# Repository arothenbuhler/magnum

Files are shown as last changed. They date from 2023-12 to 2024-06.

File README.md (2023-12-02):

# Magnum
Magnum is a development/debug probe supporting SWD and serial communication.

This is not your regular debug probe as it has some neat features that other
debug probes don't provide. Magnum was designed to pack as many useful features
as possible into one small USB-dongle and minimizing the needed cables.

## Pass-through USB
Magnum connects to your PC via a USB-C cable. It has an onboard hub with a
USB-C plug, meaning that if your target also has a USB-C connector, you can
plug Magnum directly into your target. You now get all of the probe
functionality AND the target's USB connection with only a single cable. Due
to the onboard hub, it looks as though Magnum passes the USb connection
straight through.

## Target power managment
When using the target USB-C plug, Magnum can measure power on the VBUS supply
lines. This is useful to do simple power measurements. If the measurement
bandwidth is not high enough or if one simply want to "look" at the current as
a waveform (i.e. with a scope), there is an analog output that can be directly
connected to a scope or other analog measurement device. This analog output
reflects the real-time measured current as a voltage.

Additionally, Magnum allows to control the target's power using a load switch.
The USB hub has control over this too, so in normal operation if the host
detects an issue and attempts to reset the device, the hub's power control pin
will cycle target power. This can of course interfere with debugging and so
Magnum allows to override the hub's power control so the user can dictate when
power to the target is on or off. The default configuration is to let the USB
hub (and therefore the host) control the power state.

## Integrated serial port
A lot of debug probes don't provide an extra serial port. Not Magnum, it
integrates a debug serial port and makes it available on the same USB interface
with all other probe functionality. This serial port is part of the 10-pin
debug connector along with SWD and SWO.

One of the key differentiators, however, is that this debug serial port is also
mapped onto the target's USB-C connector's SBU lines. The SBU lines are not
defined in the USB-C specification and can be used/defined by the device
manufacturer. This means that if the target device connects its debug UART
signals to the SBU lines, then Magnum can act as a simple serial dongle with no
extra cables needed. It goes without saying that this also implies that the
debug UART lines can now be accessed without opening the target's enclosure.

Magnum uses the USB-C connector's CC lines to detect the connector orientation
and then automatically swaps the Rx/Tx signals.

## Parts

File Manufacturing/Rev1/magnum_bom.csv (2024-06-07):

Comment | Designator | Footprint | LCSC
18pF | C1,C2,C17,C21 | Redhill_lib:C_0402_1005Metric | C1549
0.1uF | C3,C4,C5,C6,C7,C8,C12,C13,C14,C16,C22,C23,C24,C25,C26,C27,C28,C30,C31,C32,C33 | Redhill_lib:C_0402_1005Metric | C1525
1nF | C35,C36 | Redhill_lib:C_0402_1005Metric | C1523
1uF | C18,C19,C20,C29,C34,C37,C38,C40,C42,C43 | Redhill_lib:C_0402_1005Metric | C52923
10uF | C9,C10,C11,C15,C39,C41 | Redhill_lib:C_0603_1608Metric | C96446
LTST-C190GKT | D2 | Redhill_lib:LED_0603_1608Metric | C125093
LTST-C190KFKT | D3 | Redhill_lib:LED_0603_1608Metric | C157740
LTST-C190TBKT | D4 | Redhill_lib:LED_0603_1608Metric | C125096
DT1240A-08LP3810 | D5 | Redhill_lib:UDFN-9_1.0x3.8mm_P0.5mm | C526598
SP0504BAJT | D6,D7 | Redhill_lib:SOT-353_SC-70-5 | C5116451
LED_DUAL_RED_GREEN_LTST-C235KGKRKT | D8 | Redhill_lib:LED_LiteOn_LTST-C155GEKT | C913080
6A, 33Ohm @100MHz | FB1,FB2 | Redhill_lib:R_1206_3216Metric | C74090
BLM15AG601SN1D | FB3,FB4,FB5,FB6,FB7,FB8 | Redhill_lib:R_0402_1005Metric | C76884
MountingHole | H1,H2 | MountingHole:MountingHole_2.5mm
USB_C_Receptacle_USB2.0 | J1 | Redhill_lib:USB_C_Receptacle_GCT_USB4105-xx-A_16P_TopMnt_Horizontal | C3025063
CONN_Header_2Pin_2.54mmPitch | J3 | Redhill_lib:Header_2Pin_Pitch2.54mm_Drill0.8mm | C5116481
CONN_USB4155_USB_C_Plug | J5 | Redhill_lib:GCT_USB4155-03-C_REVA | C5183853
ARM_SWD_SERIAL_10 | J4,J6 | Redhill_lib:PinHeader_2x05_P1.27mm_Vertical_SMD | C2874168
2N7002 | Q1,Q2,Q3,Q4 | Redhill_lib:SOT-23 | C5224215
1M | R1 | Redhill_lib:R_0402_1005Metric | C138033
27 | R12,R13,R21 | Redhill_lib:R_0402_1005Metric | C5151586
100 | R16,R17,R19,R25,R29,R52 | Redhill_lib:R_0402_1005Metric | C471762
0 | R2 | Redhill_lib:R_0402_1005Metric | C17168
56k | R3,R4,R6,R22,R44,R51 | Redhill_lib:R_0402_1005Metric | C25796
0.02 | R30 | Redhill_lib:R_1206_3216Metric | C2889962
51 | R9,R10,R24,R32,R33,R34,R35,R36,R37,R41,R42,R43,R47,R48 | Redhill_lib:R_0402_1005Metric | C2759480
12k | R5,R14,R15 | Redhill_lib:R_0402_1005Metric | C25752
10k | R7,R8,R11,R18,R20,R23,R26,R27,R28,R31,R38,R39,R40,R45,R46,R49,R50 | Redhill_lib:R_0402_1005Metric | C25744
EMI2121MTTAG | U1,U9 | Redhill_lib:WDFN-8-1EP_2x2.2mm_P0.5mm_EP0.80x0.54 | C464146
FUSB302BMPX | U10 | Redhill_lib:WQFN-14-1EP_2.5x2.5mm_P0.5mm_EP1.45x1.45mm | C132291
FUSB303BTMX | U11 | Redhill_lib:Texas_X2QFN-12_1.6x1.6mm_P0.4mm
IC_MEM_AT24CSW010-STUM-T | U12 | Redhill_lib:SOT-23-5 | C5224830
IC_USB2412-DZK | U2 | Redhill_lib:QFN-28-1EP_5x5mm_P0.5mm_EP3.35x3.35mm_ThermalVias | C220647
3.3V, 300mA | U3 | Redhill_lib:TSOP-5_1.65x3.05mm_P0.95mm | C603505
W25Q32JVZP | U4 | Redhill_lib:USON-8_2x3mm | C2843335
RP2040 | U5 | Redhill_lib:QFN-56-1EP_7x7mm_P0.4mm_EP3.2x3.2mm_ThermalVias | C2040
IC_INA225 | U6 | Redhill_lib:VSSOP-8_3.0x3.0mm_P0.65mm | C485974
AP22814AW5 | U7 | Redhill_lib:SOT-23-5 | C2680321
IC_FSUSB42MUX | U8 | Redhill_lib:MSOP-10_3x3mm_P0.5mm | C11355
24MHz | Y1 | Redhill_lib:Crystal_SMD_0603-4Pin_6.0x3.5mm | C2449842
Crystal_ECS-120-20-33_12MHz | Y2 | Redhill_lib:Crystal_SMD_3225-4Pin_3.2x2.5mm | C9002

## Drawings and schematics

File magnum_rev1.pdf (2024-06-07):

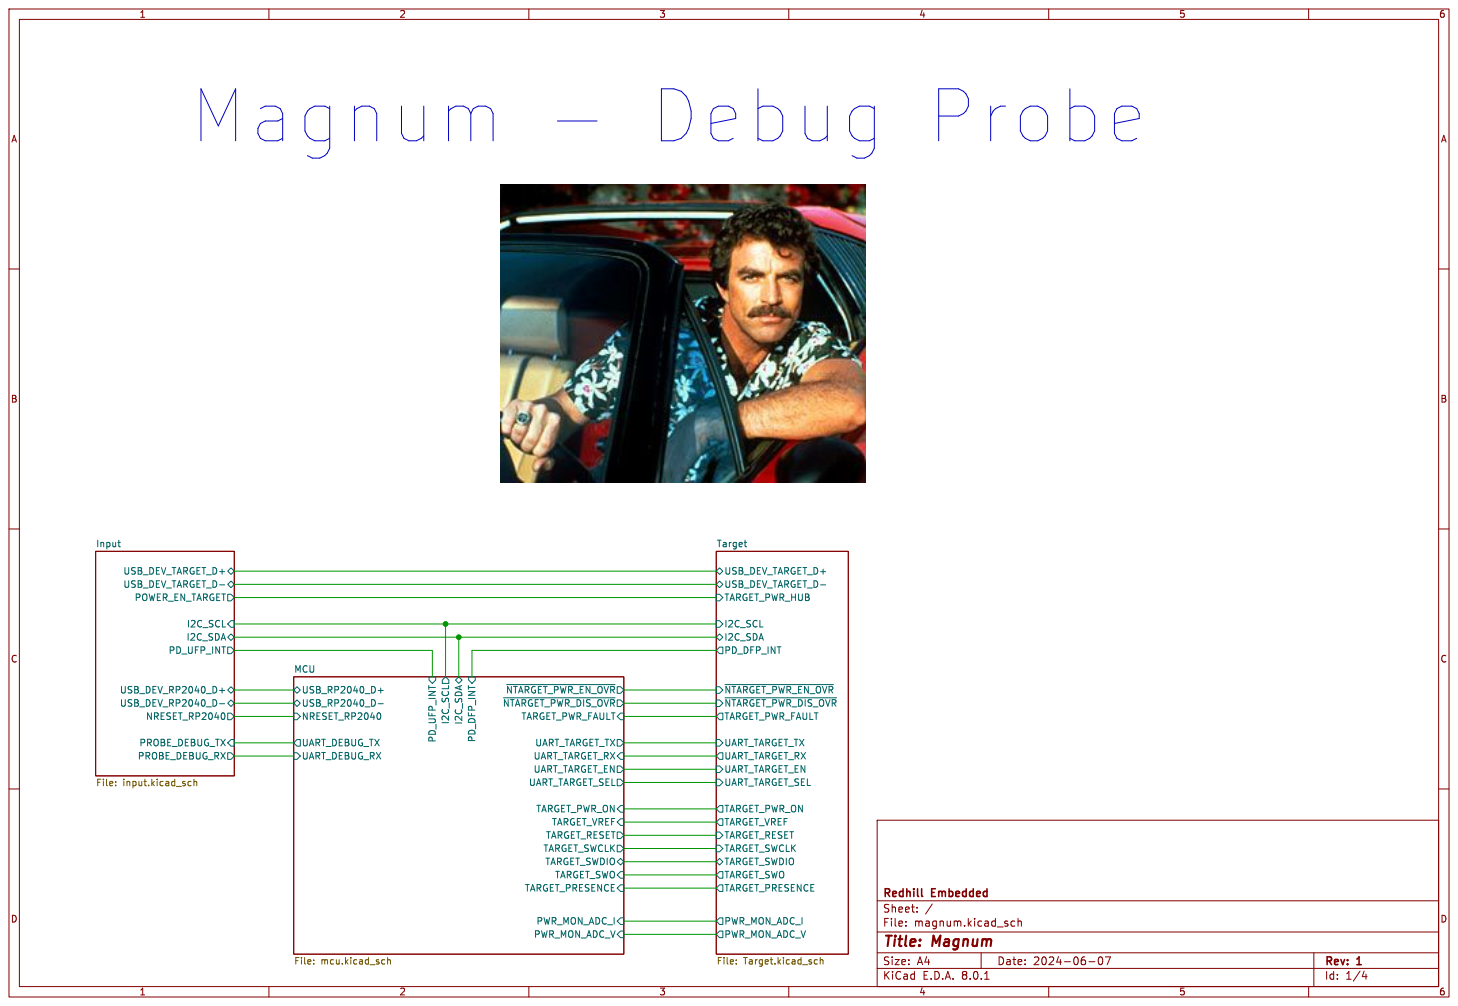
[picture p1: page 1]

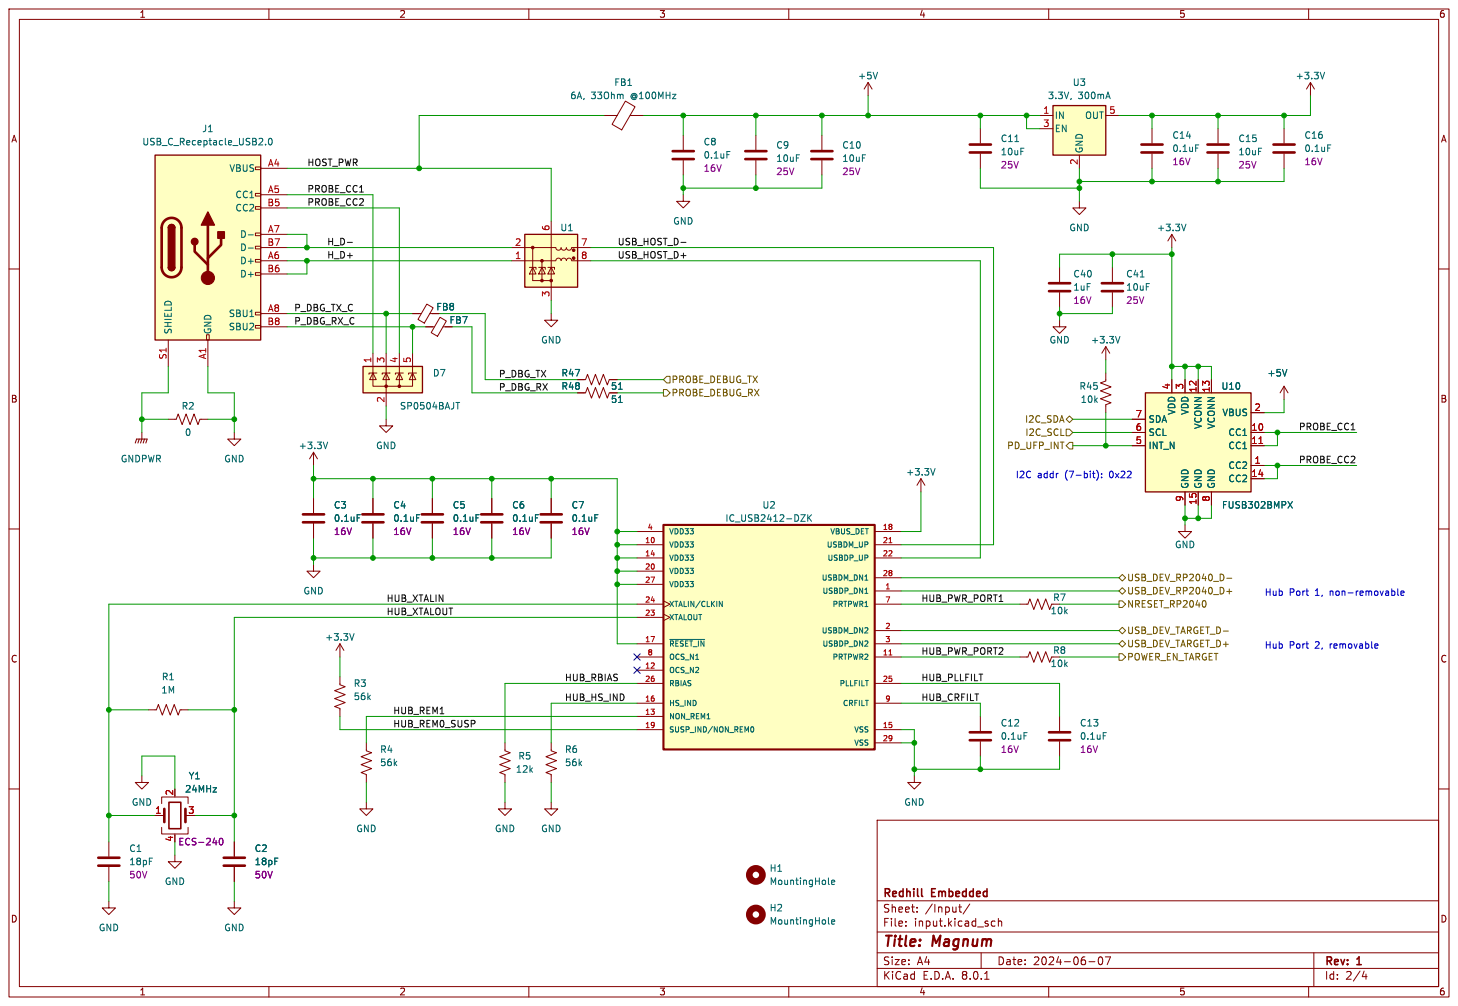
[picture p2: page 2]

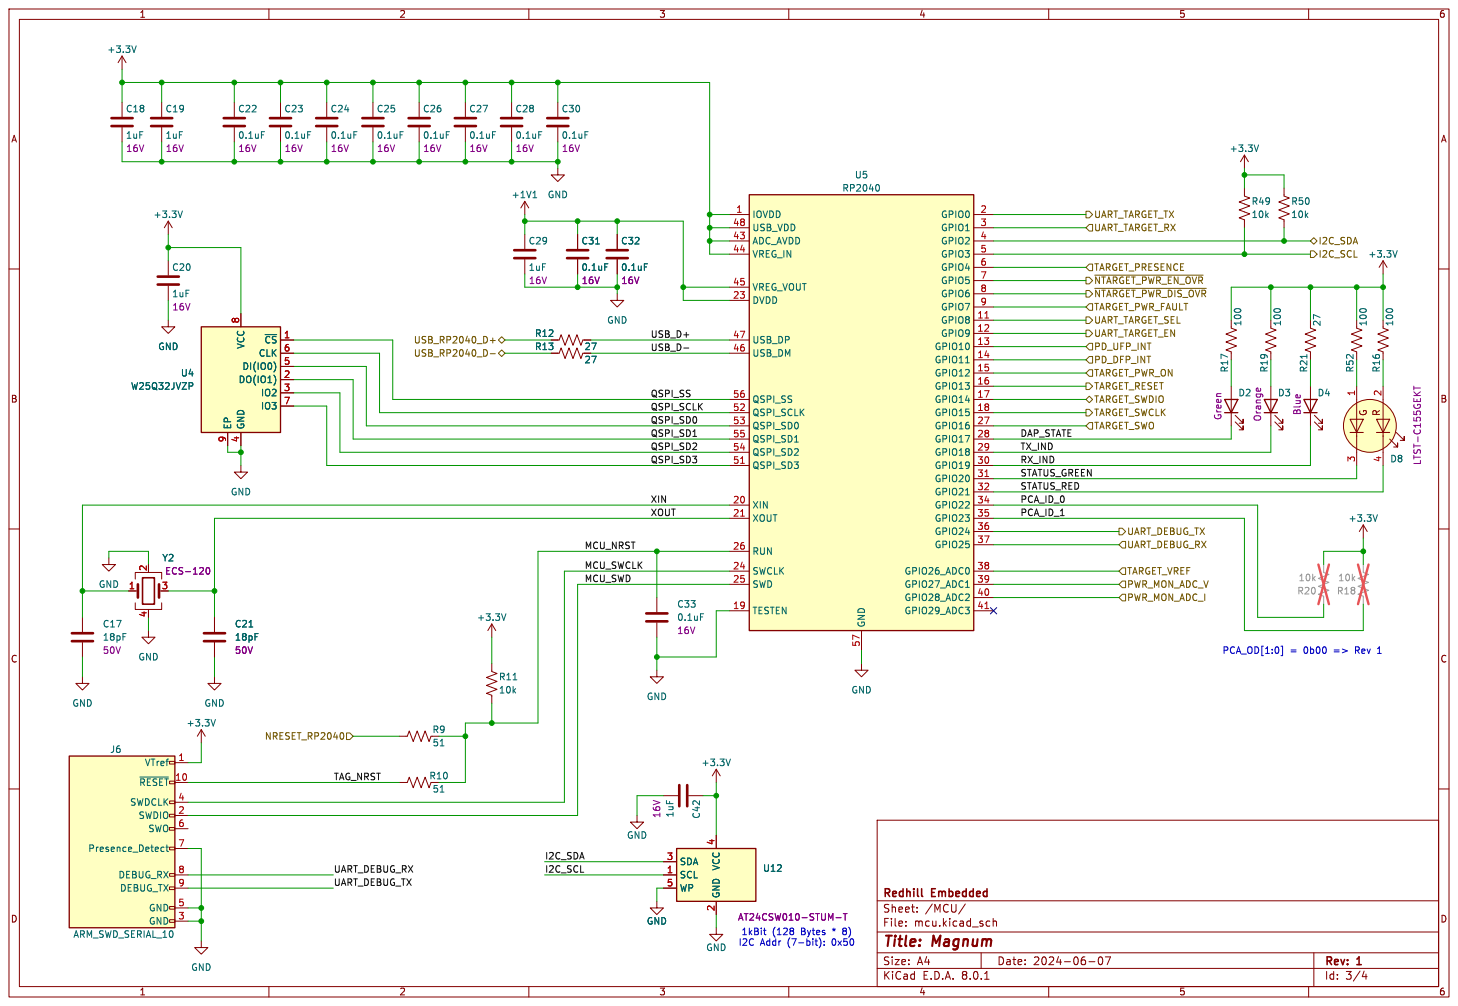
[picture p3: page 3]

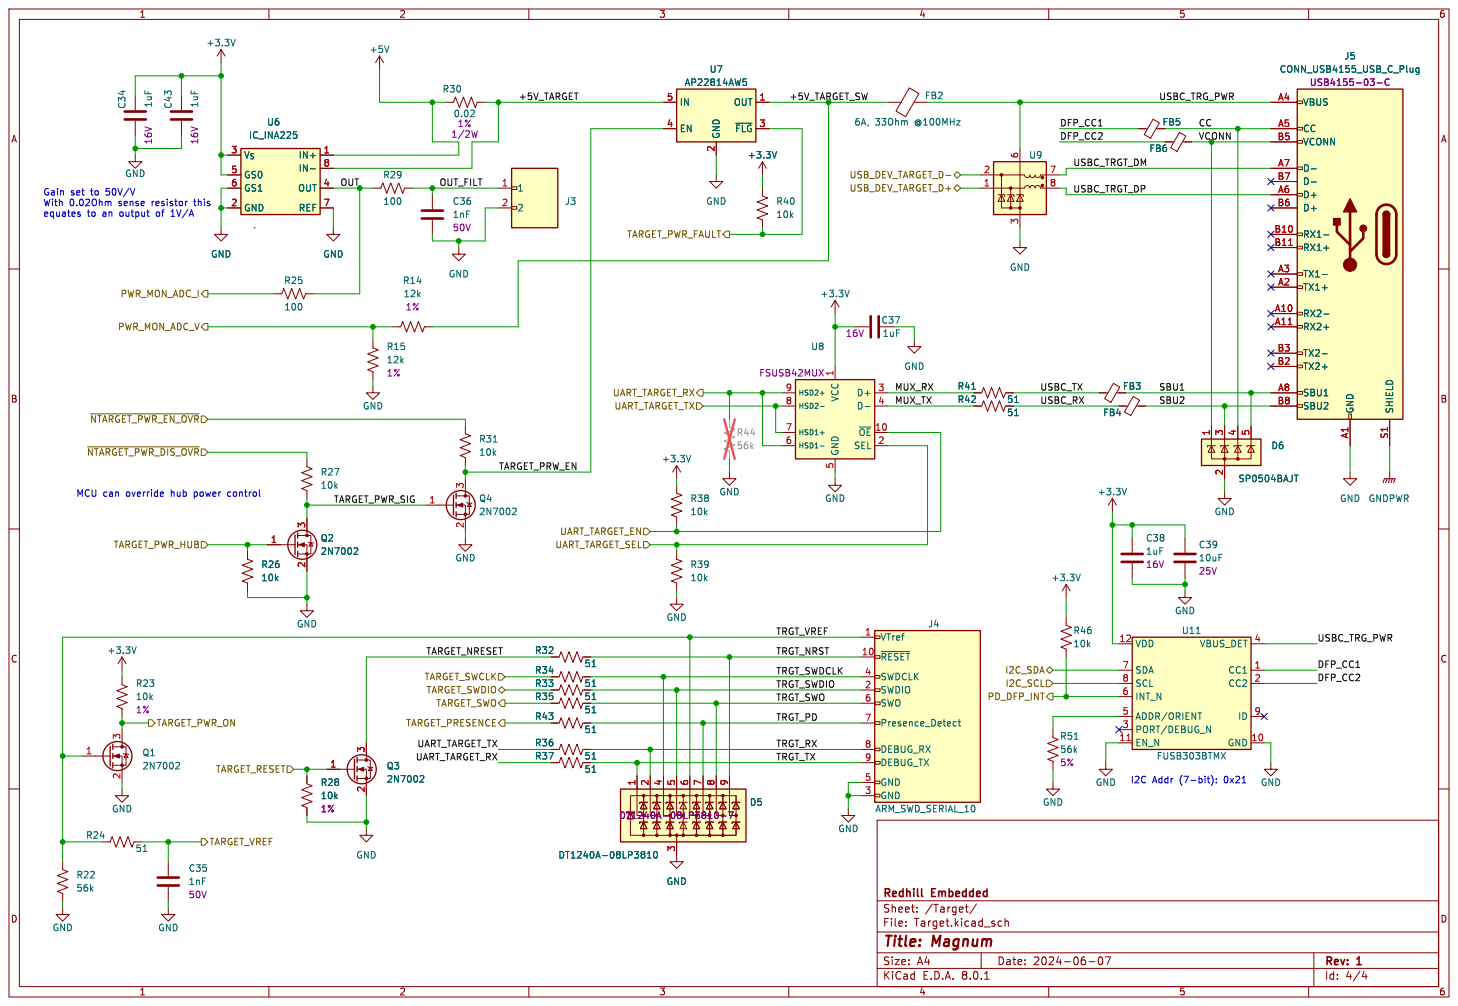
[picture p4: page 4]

VTref 1 ~{RESET} 10 SWDIO 2 GND 3 SWDCLK 4 GND 5 SWO 6 Presence_Detect 7 DEBUG_RX 8 DEBUG_TX 9
